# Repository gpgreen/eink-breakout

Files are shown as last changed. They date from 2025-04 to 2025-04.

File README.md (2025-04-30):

# Eink-Breakout
Kicad project for a [Dalian Good Display](https://www.good-display.com/) Epaper breakout board. The
display [GDEW042T2](https://www.good-display.com/product/226.html) has
a 24pin flat panel cable. The display is controlled with the SPI bus,
so the display SPI pins are passed to a JST PH connector.

Note: R1 is shown on the datasheet example circuit. It is not needed so should not be
populated on the board.

## Functions
The main function of the board is to translate the signals from the
flat panel cable to the JST PH connector. The JST connector has
signals for the SPI bus, D/C, Busy from the eink display. Also power
and ground at 3.3VDC.

The rest of the conductors on the flat panel cable are connected as
shown in the datasheet example wiring. There is no bus translation,
everything is set at 3.3VDC.

 - [Schematic](eink-breakout-sch-v1.1.pdf)

## PCB

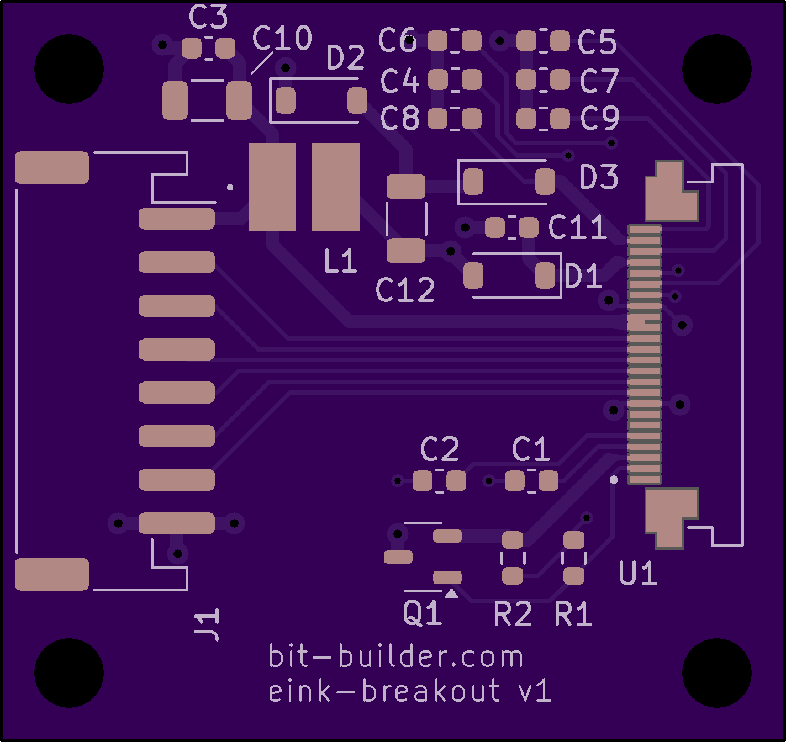
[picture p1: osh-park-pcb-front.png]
PCB front
 - 
 - [Parts List](eink-breakout.ods)

## License

Licensed under

- MIT license ([LICENSE-MIT](LICENSE-MIT) or http://opensource.org/licenses/MIT)

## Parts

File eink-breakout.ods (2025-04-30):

Reference | Value | Footprint | Datasheet | Qty | DNP | Exclude from BOM | Exclude from Board | Digikey PN
C1,C2,C3,C4,C5,C6,C7,C8,C9,C11 | 1uF/50V | Capacitor_SMD:C_0603_1608Metric |  | 10 |  |  |  | 2679-C0603X5R500-105KNP-CT-ND
C10,C12 | 4.7uF/50V | Capacitor_SMD:C_1206_3216Metric |  | 2 |  |  |  | 2679-AGC1206X7R500-475KXE-CT-ND
D1,D2,D3 | DIODE SCHOTTKY 30V 500MA SOD123, MBR0530 | Diode_SMD:D_SOD-123 | ~ | 3 |  |  |  | 1655-MBR0530CT-ND
H1,H2,H3,H4 | MountingHole | MountingHole:MountingHole_3.2mm_M3_DIN965 | ~ | 4 |  | Excluded from BOM
J1 | MCU | Connector_JST:JST_PH_S8B-PH-SM4-TB_1x08-1MP_P2.00mm_Horizontal | ~ | 1 |  |  |  | 455-B8B-PH-SM4-TBCT-ND
L1 | 10uH | IFSC1515AHER100M01:IND_IFSC_1515AH_VIS-M | ~ | 1 |  |  |  | 541-1406-1-ND
Q1 | IRLML0100TRPBF | Package_TO_SOT_SMD:SOT-23-3 |  | 1 |  |  |  | IRLML0100TRPBFCT-ND
R1 | 10Kohm | Resistor_SMD:R_0603_1608Metric |  | 1 | X
R2 | 0.47ohm | Resistor_SMD:R_0603_1608Metric |  | 1 |  |  |  | P.47AHCT-ND
U1 | WAVESHARE_4_2_INCH_EINK_DISPLAY | SFV24R_4STBE1HLF:AMPHENOL_SFV24R-4STBE1HLF |  | 1 |  |  |  | 609-5202-1-ND

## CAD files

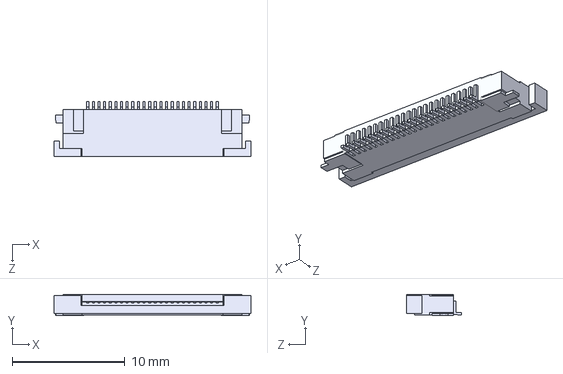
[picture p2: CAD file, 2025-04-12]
SFV24R_4STBE1HLF/SFV24R-4STBE1HLF.step
17.5 x 1.87 x 4.90 mm

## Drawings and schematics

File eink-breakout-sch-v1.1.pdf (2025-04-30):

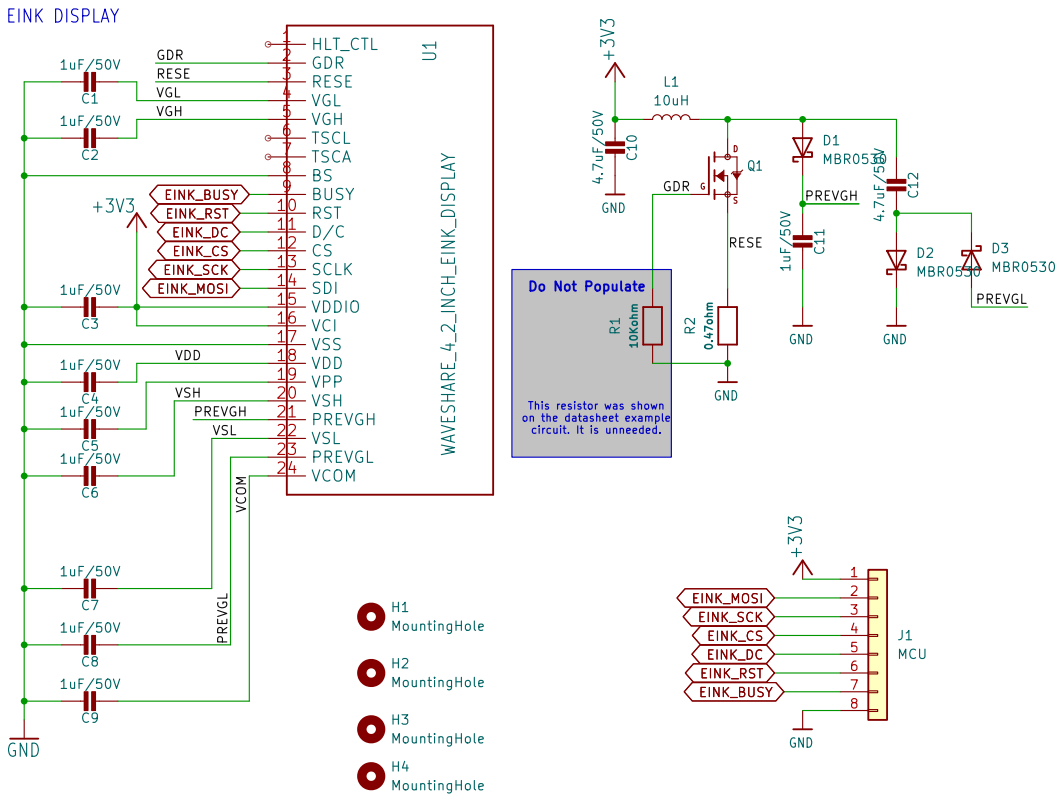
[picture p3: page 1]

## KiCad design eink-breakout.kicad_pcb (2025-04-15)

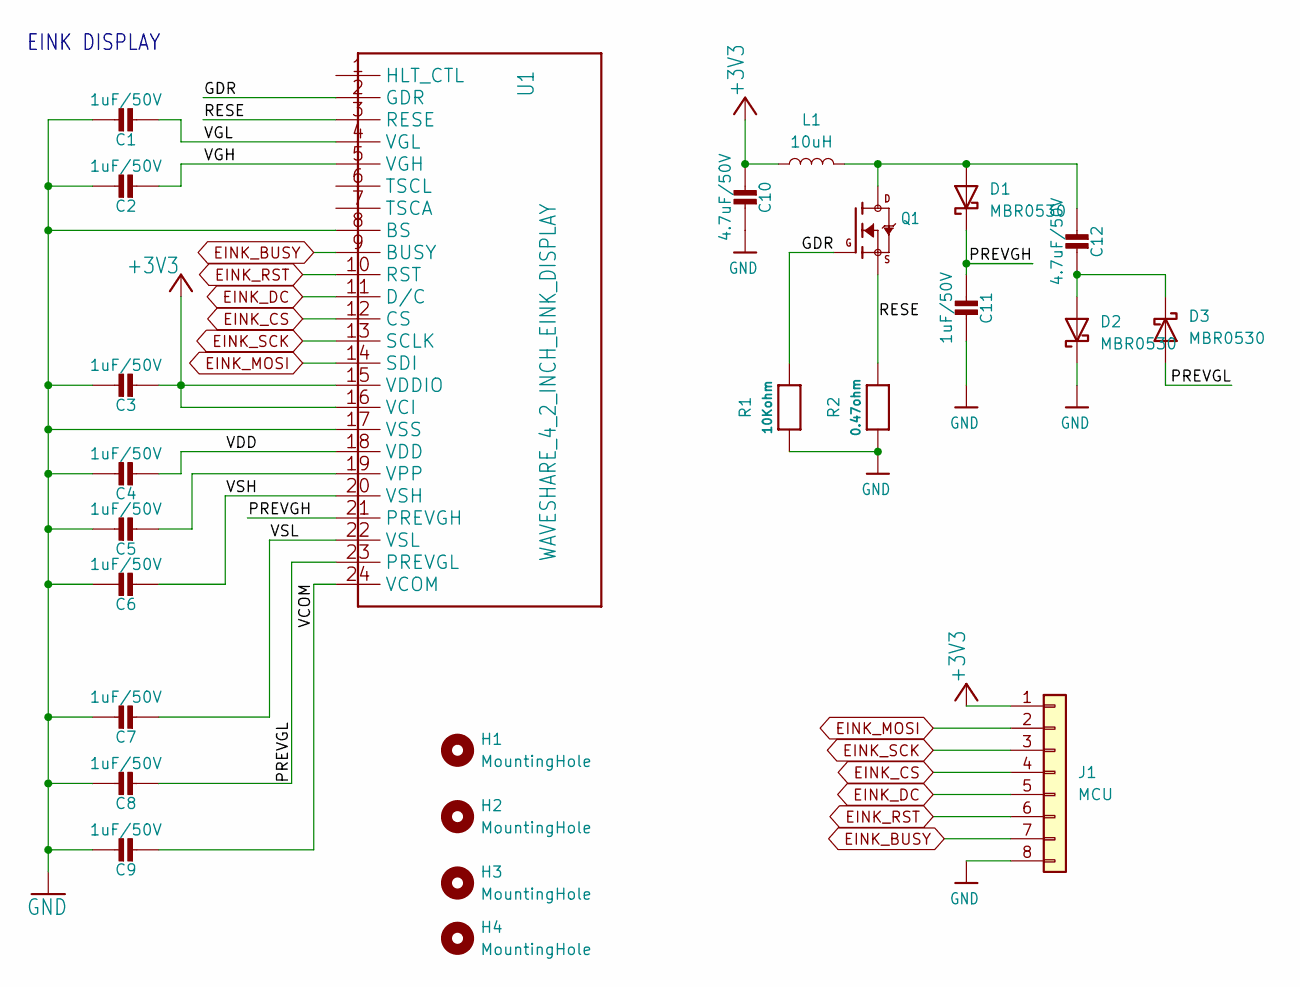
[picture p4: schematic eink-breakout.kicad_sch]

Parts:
C1, C2, C3, C4, C5, C6, C7, C8, C9, C11: 1uF/50V; C_0603_1608Metric
C10, C12: 4.7uF/50V; C_1206_3216Metric
D1, D2, D3: MBR0530; D_SOD-123
H1, H2, H3, H4: MountingHole; MountingHole_3.2mm_M3_DIN965
J1: MCU; JST_PH_S8B-PH-SM4-TB_1x08-1MP_P2.00mm_Horizontal
L1: 10uH; IND_IFSC_1515AH_VIS-M
Q1: IRLML0100; SOT-23-3
R1: 10Kohm; R_0603_1608Metric
R2: 0.47ohm; R_0603_1608Metric
U1: WAVESHARE_4_2_INCH_EINK_DISPLAY; AMPHENOL_SFV24R-4STBE1HLF

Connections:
+3V3: C3.2, C10.1, J1.1, L1.1, U1.15 (VDDIO), U1.16 (VCI)
/GDR: Q1.1 (G), R1.1, U1.2 (GDR)
/PREVGH: C11.1, D1.1 (K), U1.21 (PREVGH)
/PREVGL: C8.2, D3.2 (A), U1.23 (PREVGL)
/RESE: Q1.2 (S), R2.1, U1.3 (RESE)
/VCOM: C9.2, U1.24 (VCOM)
/VDD: C4.2, U1.18 (VDD)
/VGH: C2.2, U1.5 (VGH)
/VGL: C1.2, U1.4 (VGL)
/VSH: C6.2, U1.20 (VSH)
/VSL: C7.2, U1.22 (VSL)
EINK_BUSY: J1.7, U1.9 (BUSY)
EINK_CS: J1.4, U1.12 (CS)
EINK_DC: J1.5, U1.11 (D/C)
EINK_MOSI: J1.2, U1.14 (SDI)
EINK_RST: J1.6, U1.10 (RST)
EINK_SCK: J1.3, U1.13 (SCLK)
GND: C1.1, C2.1, C3.1, C4.1, C5.1, C6.1, C7.1, C8.1, C9.1, C10.2, C11.2, D2.1 (K), J1.8, R1.2, R2.2, U1.8 (BS), U1.17 (VSS)
unnamed: C12.1, D1.2 (A), L1.2, Q1.3 (D)
unnamed: C12.2, D2.2 (A), D3.1 (K)
unnamed: C5.2, U1.19 (VPP)

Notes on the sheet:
EINK DISPLAY

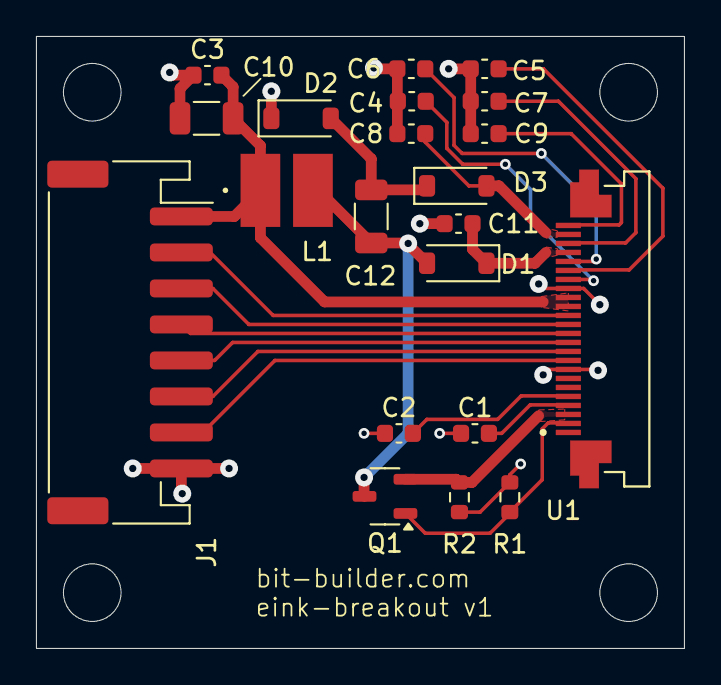
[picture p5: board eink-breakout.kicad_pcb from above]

Board: 2 copper layers, 36.0 x 34.0 mm, 25 parts (0 on the bottom side), 21 nets.

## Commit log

2025-04-15 Ready for gerbers
    [eink-breakout.kicad_pcb]
2025-04-20 Updated README.md
    Centered symbols in schematic
    Added png of pcb board
    Renamed license file
    [eink-breakout.kicad_sch]
2025-04-30 DNP of R1
    Datasheet showed R1 attached to gate of mosfet, this was
    incorrect. Fixed in this version by not populating footprint.
    [eink-breakout.kicad_sch, eink-breakout.ods]
2025-04-30 Updated url of schematic
